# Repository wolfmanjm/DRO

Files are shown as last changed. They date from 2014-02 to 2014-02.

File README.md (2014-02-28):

DRO
===

A home made DRO for a lathe.

Uses an I2C LCD with two buttons.

Uses 
AS5306 linear encoder http://www.ams.com/ger/Products/Position-Sensors/Linear-Incremental-Magnetic-Position-Sensors/AS5306

1.2mm pole length mag strip http://www.ams.com/ger/Products/Position-Sensors/Magnets/AS5000-MS12-250

PCB from here http://www.thingiverse.com/thing:1409
or http://www.thingiverse.com/thing:5608
I had the latter sent to OSHPark and got three boards made

The components I got from Digikey
The magnetic strip I got direct from AMS  http://www.ams.com

I made a little slider to hold the board a fixed distance from the strip as required, these are
included in this repo.

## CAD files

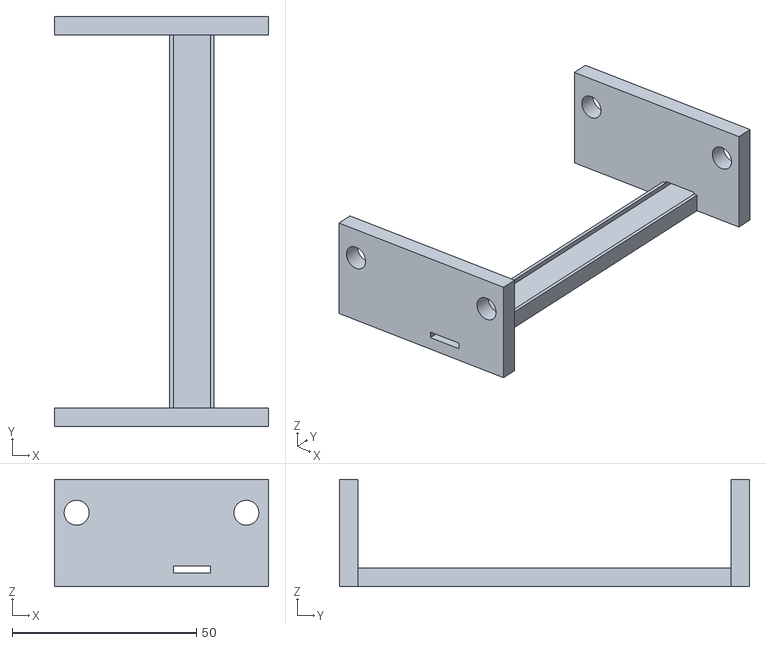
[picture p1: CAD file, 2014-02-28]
objects/linear-encoder-rail.stl
58.0 x 111.2 x 29.0

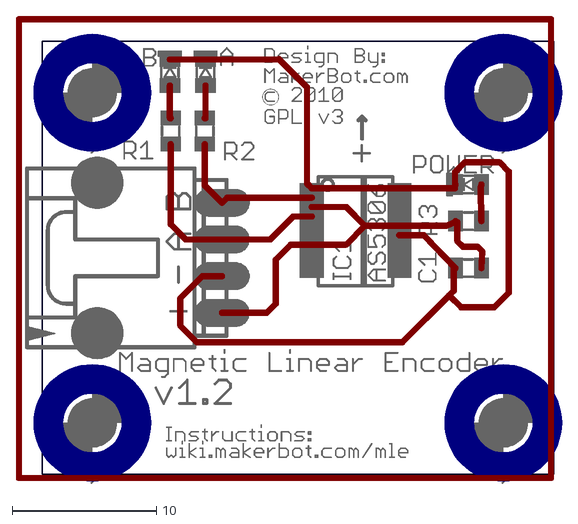
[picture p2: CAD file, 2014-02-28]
objects/magnetic-linear-encoder.dxf
37.8 x 32.3

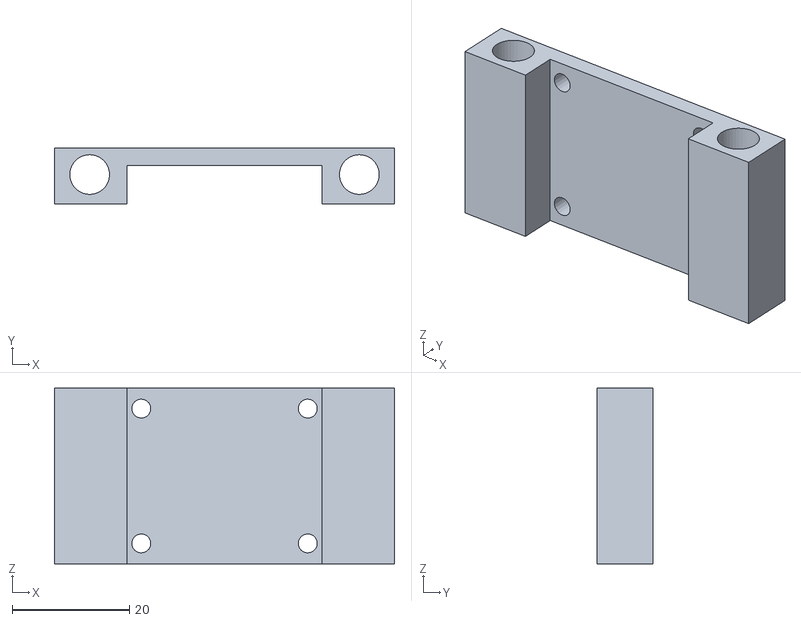
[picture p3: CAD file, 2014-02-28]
objects/linear-encoder-carriage.stl
58.0 x 9.50 x 30.0

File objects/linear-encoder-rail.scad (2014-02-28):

use <myLibs.scad>

mm= 25.4;
mst= 1.8; // thickness of magnetic strip
msw= 10; // width of magnetic strip
carriage_length= 30;
rail_length= 3*mm + carriage_length;
rail_width= 20;
rail_depth= 5;
rail_dia= 1/4*mm;
rail_height= 35;
pcb_width= 35.4;
sep= rail_width/2 + 13;
end_width= 58;
offset= 10-5+2.2+1.02;

//rotate([90, 0, 0])
difference() {
	union() {
		%translate([0, 0, rail_height/2-3])  carriage();
		rail();
	}
	#translate([sep, rail_length/2+6, rail_height/2]) rotate([90, 0, 0]) hole(rail_dia, rail_length+10, 0.2);
	#translate([-sep, rail_length/2+6, rail_height/2]) rotate([90, 0, 0]) hole(rail_dia, rail_length+10, 0.2);
}

module board(ht) {
	chipoffset= 9.4;
	translate([-pcb_width-0.4, -30-1.7,ht])  import("magnetic-linear-encoder.dxf");
	// chip
	translate([chipoffset-4.4/2, 0, ht-0.9])  cube(size=[4.4,6.5,2.71], center=true);
	// socket
	translate([-pcb_width/2+8, 0, ht+3.0])  cube(size=[6,7,5], center=true);
}

module carriage() {
	l= carriage_length;
	w= pcb_width;
	h= 3;
	cw= end_width;

	%board(-9.3 + 0.4); // <= 0.4mm above strip
	difference() {
		union() {
	    	cube(size=[cw, l, h], center=true);
	    	translate([-cw/2, -l/2, 0])  cube(size=[rail_dia+6, l, 8], center=false);
	    	translate([cw/2-(rail_dia+6), -l/2, 0])  cube(size=[rail_dia+6, l, 8], center=false);
	    }
	    #translate([-w/2+3.5, -l/2+3.5, -7])  hole(3, 10);
	    translate([w/2-3.5, -l/2+3.5, -7])   hole(3, 10);
	    translate([-w/2+3.5, l/2-3.5, -7])   hole(3, 10);
	    translate([w/2-3.5, l/2-3.5, -7])    hole(3, 10);
	}
}

module rail() {
	l= rail_length;
	w= rail_width-8;
	t= rail_depth;

	difference() {
		union() {
			translate([offset, 0, 0]) cube(size=[w, l, t], center=true);
			slides();
		}
		#translate([offset, 0, t/2-mst/4+0.05])  cube(size=[msw, l+10, mst], center=true);
	}
}

module slides() {
	l= rail_length;
	w= end_width;
	t= 5;
	h= rail_height-6;
	translate([0, l/2, h/2-rail_depth/2])  cube(size=[w, t, h], center=true);
	translate([0, -l/2, h/2-rail_depth/2])  cube(size=[w, t, h], center=true);
}

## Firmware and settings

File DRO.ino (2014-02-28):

// DRO.ino
//#define ENCODER_OPTIMIZE_INTERRUPTS
#include <Encoder.h>

#include "utility/twi.h"
#include "Wire.h"

#include "LCDSmoothiePanel.h"



#define LE_ENCA 2
#define LE_ENCB 3

Encoder lme(LE_ENCA, LE_ENCB);

int readEncoderDelta(char &old_AB)
{
    static char enc_states[] = {0, -1, 1, 0, 1, 0, 0, -1, -1, 0, 0, 1, 0, 1, -1, 0};
    char state;
    old_AB <<= 2;                   //remember previous state
    old_AB |= ( digitalRead(LE_ENCA) + ( digitalRead(LE_ENCB) * 2 ) );  // add current state
    state = enc_states[(old_AB & 0x0f)];
    return state;
}

void clear() {
    lcd_clear();
    // Print a message to the LCD.
    lcd_setCursor(0, 0);
    lcd_print(".....DRO.....");
}

void setup()
{
    lcd_init();
    clear();
}

long pos = 0;
long lastpos = 0;
unsigned long lt1 = 0, lt2 = 0;
char enc1= 0, enc2= 0;
bool inches= false;
const float umperthou= 0.039370079;
bool display= true;

void loop()
{
    char buf[10];

    pos= lme.read();

    if(display || (pos != lastpos && millis() > lt1)) {

        long p= pos * 15; // one step is 15um with the correct mag strip
        lcd_setCursor(0, 1);
        if(inches){
            long thou= round(p*umperthou);
            lcd_printf("%10ld thou", thou);
            lcd_setCursor(0, 2);
            lcd_printf("%6ld.%03ld inch", thou/1000, abs(thou%1000));
        }else{
            lcd_printf("%10ld um", p);
            lcd_setCursor(0, 2);
            lcd_printf("%6ld.%03ld mm", p/1000, abs(p%1000));
        }
        lcd_setCursor(0, 3);
        lcd_printf("%10ld", pos);

        lastpos = pos;
        lt1 = millis() + 100;
        display= false;
    }

    if(millis() > lt2) {
        // read buttons
        uint8_t b= lcd_readButtons();
        if(b & BUTTON_LEFT) {
            //pos= 0;
            lme.write(0);
            display= true;
        }
        if(b & BUTTON_PAUSE) {
            inches= !inches;
            clear();
            display= true;
            lcd_led(inches?2:0);
        }
        lt2= millis() + 200;
    }

}

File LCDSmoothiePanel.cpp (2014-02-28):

/*
   drive a SmoothiePanel from Arduino
   courtesy of Logxgen from Smoothie/src/modules/utils/panel/panels/Smoothiepanel.cpp
*/
#if defined(ARDUINO) && (ARDUINO >= 100) //scl
#include "Arduino.h"
#else
#include "WProgram.h"
#endif

#include "utility/twi.h"
#include "Wire.h"

#include "LCDSmoothiePanel.h"

#define PCA9505_ADDRESS 0x40
#define PCA9634_ADDRESS 0x50

// commands
#define LCD_CLEARDISPLAY 0x01
#define LCD_RETURNHOME 0x02
#define LCD_ENTRYMODESET 0x04
#define LCD_DISPLAYCONTROL 0x08
#define LCD_CURSORSHIFT 0x10
#define LCD_FUNCTIONSET 0x20
#define LCD_SETCGRAMADDR 0x40
#define LCD_SETDDRAMADDR 0x80

// flags for display entry mode
#define LCD_ENTRYRIGHT 0x00
#define LCD_ENTRYLEFT 0x02
#define LCD_ENTRYSHIFTINCREMENT 0x01
#define LCD_ENTRYSHIFTDECREMENT 0x00

// flags for display on/off control
#define LCD_DISPLAYON 0x04
#define LCD_DISPLAYOFF 0x00
#define LCD_CURSORON 0x02
#define LCD_CURSOROFF 0x00
#define LCD_BLINKON 0x01
#define LCD_BLINKOFF 0x00

// flags for display/cursor shift
#define LCD_DISPLAYMOVE 0x08
#define LCD_CURSORMOVE 0x00
#define LCD_MOVERIGHT 0x04
#define LCD_MOVELEFT 0x00

// flags for function set
#define LCD_8BITMODE 0x10
#define LCD_4BITMODE 0x00
#define LCD_2LINE 0x08
#define LCD_1LINE 0x00
#define LCD_5x10DOTS 0x04
#define LCD_5x8DOTS 0x00

// flags for backlight control
#define LCD_BACKLIGHT 0x08
#define LCD_NOBACKLIGHT 0x00


#define LCD_WRITE       0x00
#define LCD_READ        0x01
#define LCD_ACK         0x01

static inline void wiresend(uint8_t x) {
#if ARDUINO >= 100
  Wire.write((uint8_t)x);
#else
  Wire.send(x);
#endif
}

static inline uint8_t wirerecv(void) {
#if ARDUINO >= 100
  return Wire.read();
#else
  return Wire.receive();
#endif
}

void wait_ms(int n) {
	delay(n);
}

void i2c_write(int addr, char *data, int n, bool repeated= false) {
	Wire.beginTransmission(addr>>1);
    for (int i = 0; i < n; ++i) {
    	wiresend(*data++);
    }
    Wire.endTransmission();
}

void i2c_read(int addr, char *buf, int n= 1) {
  	Wire.requestFrom(addr>>1, n);
  	for (int i = 0; i < n; ++i) {
  		*buf++ = wirerecv();
  	}
}

void pca9505_write(int address, char reg, char val) {
    const int expander = PCA9505_ADDRESS | (address & 0x0E);
    char cmd[2];

    cmd[0] = reg;
    cmd[1] = val;
    i2c_write(expander, cmd, 2);
}

char pca9505_read(int address, char reg){
    const int expander = PCA9505_ADDRESS | (address & 0x0E);
    char cmd[1];

    cmd[0] = 0x04;
    i2c_write(expander, cmd, 1, false);
    i2c_read(expander, cmd, 1);
    return cmd[0];
}

void pca9634_init(int address){
    const int leds = PCA9634_ADDRESS | (address & 0x0E);
    char cmd[2];

    // initialize led controller
    cmd[0] = 0x00;
    cmd[1] = 0x00;
    i2c_write(leds, cmd, 2);
    cmd[0] = 0x01;
    cmd[1] = 0x02;
    i2c_write(leds, cmd, 2);
    cmd[0] = 0x0C;
    cmd[1] = 0xAA;
    i2c_write(leds, cmd, 2);
    cmd[0] = 0x0D;
    i2c_write(leds, cmd, 2);
}

void pca9634_setLed(int address, char led, char val){
    const int leds = PCA9634_ADDRESS | (address & 0x0E);
    char cmd[2];

    cmd[0] = led; // lcd blue
    cmd[1] = val;
    i2c_write(leds, cmd, 2);
}
void lcdbang_writenibble(char c, bool command = false){
    const int addr = 0x40;
    char cmd[2];
    c <<= 4;
    c &= 0xF0;
    c |= 0x01;
    if(!command) c |= 0x02;

    cmd[0] = 0x0C;
    cmd[1] = c;
    i2c_write(addr, cmd, 2);
    cmd[1] = c | 0x08;
    i2c_write(addr, cmd, 2);
    cmd[1] = c;
    i2c_write(addr, cmd, 2);
//    wait_ms(1);
}

void lcdbang_write(char c, bool command = false){
    if(command){
        lcdbang_writenibble(c, command);
    }else{
        lcdbang_writenibble(c >> 4, command);
        lcdbang_writenibble(c, command);
    }
}

void lcdbang_init(){
    const int addr = 0x40;
    char cmd[2];
    cmd[0] = 0x1C;
    cmd[1] = 0x00;
    i2c_write(addr, cmd, 2);

    lcdbang_write(0x3, true);
    wait_ms(50);
    lcdbang_write(0x3, true);
    wait_ms(10);
    lcdbang_write(0x3, true);
    wait_ms(10);
    lcdbang_write(0x2, true);
    wait_ms(1);

    lcdbang_write(0x2, true);
    lcdbang_write(0x8, true);
    wait_ms(1);

    lcdbang_write(0x0, true);
    lcdbang_write(0x8, true);
    wait_ms(1);

    lcdbang_write(0x0, true);
    lcdbang_write(0x1, true);
    wait_ms(1);

    lcdbang_write(0x0, true);
    lcdbang_write(0x6, true);
    wait_ms(1);

    lcdbang_write(0x0, true);
    lcdbang_write(0x2, true);
    wait_ms(1);

    lcdbang_write(0x0, true);
    lcdbang_write(0xC, true);
    wait_ms(1);
}

void lcdbang_print(const char* msg){
    for(int i=0;msg[i];i++){
        lcdbang_write(msg[i]);
    }
}

void i2cbang_init(){
    const int addr = 0x40;
    char cmd[2];
    cmd[0] = 0x1B;
    cmd[1] = 0x3F;
    i2c_write(addr, cmd, 2);
    cmd[0] = 0x0B;
    cmd[1] = 0xC0;
    i2c_write(addr, cmd, 2);
    wait_ms(1);
}

void i2cbang_start(){
    const int addr = 0x40;
    char cmd[2];
    cmd[0] = 0x0B;
    cmd[1] = 0xBF;
    i2c_write(addr, cmd, 2);
    wait_ms(1);
    cmd[1] = 0x3F;
    i2c_write(addr, cmd, 2);
    wait_ms(1);
}

void i2cbang_stop(){
    const int addr = 0x40;
    char cmd[2];
    cmd[0] = 0x0B;
    cmd[1] = 0xBF;
    i2c_write(addr, cmd, 2);
    wait_ms(1);
    cmd[1] = 0xFF;
    i2c_write(addr, cmd, 2);
    wait_ms(1);
}

void i2cbang_writebit(bool bit){
    const int addr = 0x40;
    char cmd[2];
    cmd[0] = 0x0B;
    if(bit){
        cmd[1] = 0x7F;
    }else{
        cmd[1] = 0x3F;
    }
    i2c_write(addr, cmd, 2);
    wait_ms(1);

    if(bit){
        cmd[1] = 0xFF;
    }else{
        cmd[1] = 0xBF;
    }
    i2c_write(addr, cmd, 2);
    wait_ms(1);

    if(bit){
        cmd[1] = 0x7F;
    }else{
        cmd[1] = 0x3F;
    }
    i2c_write(addr, cmd, 2);
    wait_ms(1);

    if(bit){
        cmd[1] = 0x3F;
        i2c_write(addr, cmd, 2);
    }
    wait_ms(1);
}

char i2cbang_readbit(){
    const int addr = 0x40;
    char cmd[2];
    char res;
    cmd[0] = 0x0B;
    cmd[1] = 0x7F;
    i2c_write(addr, cmd, 2);
    wait_ms(1);

    cmd[1] = 0xFF;
    i2c_write(addr, cmd, 2);
    wait_ms(1);

    cmd[0] = 0x03;
    i2c_write(addr, cmd, 1, false);
    i2c_read(addr, cmd, 1);
    res = cmd[0];
    wait_ms(1);

    cmd[0] = 0x0B;
    cmd[1] = 0x7F;
    i2c_write(addr, cmd, 2);
    wait_ms(1);

//    cmd[1] = 0x3F;
//    i2c.write(addr, cmd, 2);
//    wait_ms(1);

    //res = (~res) & 0x40;
    return res;
}
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

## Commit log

2014-02-23 Use the arduino encoder library and interrupts for speed
2014-02-24 add inch/mm button
2014-02-28 added printable slider for DRO
    [linear-encoder-carriage.stl, linear-encoder-rail.scad, linear-encoder-rail.stl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]
